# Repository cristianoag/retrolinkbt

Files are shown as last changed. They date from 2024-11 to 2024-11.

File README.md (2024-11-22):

# RetroLinkBT
Simple adapter to allow the use of bluetooth joysticks with retro computers

## License 

Open Hardware

This work is licensed under a [Creative Commons Attribution-NonCommercial-ShareAlike 4.0 International License](http://creativecommons.org/licenses/by-nc-sa/4.0/).

* If you remix, transform, or build upon the material, you must distribute your contributions under the same license as the original.
* You may not use the material for commercial purposes.
* You must give appropriate credit, provide a link to the license, and indicate if changes were made. You may do so in any reasonable manner, but not in any way that suggests the licensor endorses you or your use.

**ATTENTION**

This project was made for the retro community and not for commercial purposes. So only retro hardware forums and individual people can build this project.

THE SALE OF ANY PART OF THIS PROJECT WITHOUT EXPRESS AUTHORIZATION IS PROHIBITED!

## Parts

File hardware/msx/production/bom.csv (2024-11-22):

Designator | Footprint | Quantity | Value | LCSC Part #
C1, C11, C12, C6, C7, C9 | 0603 | 6 | 0.1uF
C10, C4, C5, C8 | 0603 | 4 | 22uF
C3 | 0603 | 1 | 1uF
D1 | 0805 | 1 | PWR
D2 | 0805 | 1 | Port1
D3 | 0805 | 1 | BT DISC
D4, D5 | D_SOD-123 | 2 | 1N5819
F1 | 1206 | 1 | 50mA
J1 | USB_Mini-B_Lumberg_2486_01_Horizontal | 1 | USB_B_Mini
J2 | DSUB-9_Female_Horizontal_P2.77x2.84mm_EdgePinOffset4.94mm_Housed_MountingHolesOffset7.48mm | 1 | MSX Port1
JP1 | PinHeader_1x02_P2.54mm_Vertical | 1 | Fuse Bypass
JP2, JP4 | SolderJumper-2_P1.3mm_Open_RoundedPad1.0x1.5mm | 2 | Open
Q1, Q2 | SOT-23 | 2 | S8050
R1, R2 | 0603 | 2 | 1K
R10, R5, R9 | 0603 | 3 | 3.3K
R11, R3, R4, R8 | 0603 | 4 | 10K
R12, R6 | 0603 | 2 | 3.3K | C4310
R7 | 0603 | 1 | 1K | C4310
SW1 | SK12D07VG4 | 1 | SK12D07VG4
SW2 | SW_SPST_TL3342 | 1 | RESET
SW3 | SW_SPST_TL3342 | 1 | BOOT
U1 | SOIC-16_3.9x9.9mm_P1.27mm | 1 | CH340C
U2 | SOT-223-3_TabPin2 | 1 | AMS1117-3.3
U3 | ESP32-WROOM-32E | 1 | ESP32-WROOM-32E | C701341
U4, U5 | SOIC-14_3.9x8.7mm_P1.27mm | 2 | 74LS03

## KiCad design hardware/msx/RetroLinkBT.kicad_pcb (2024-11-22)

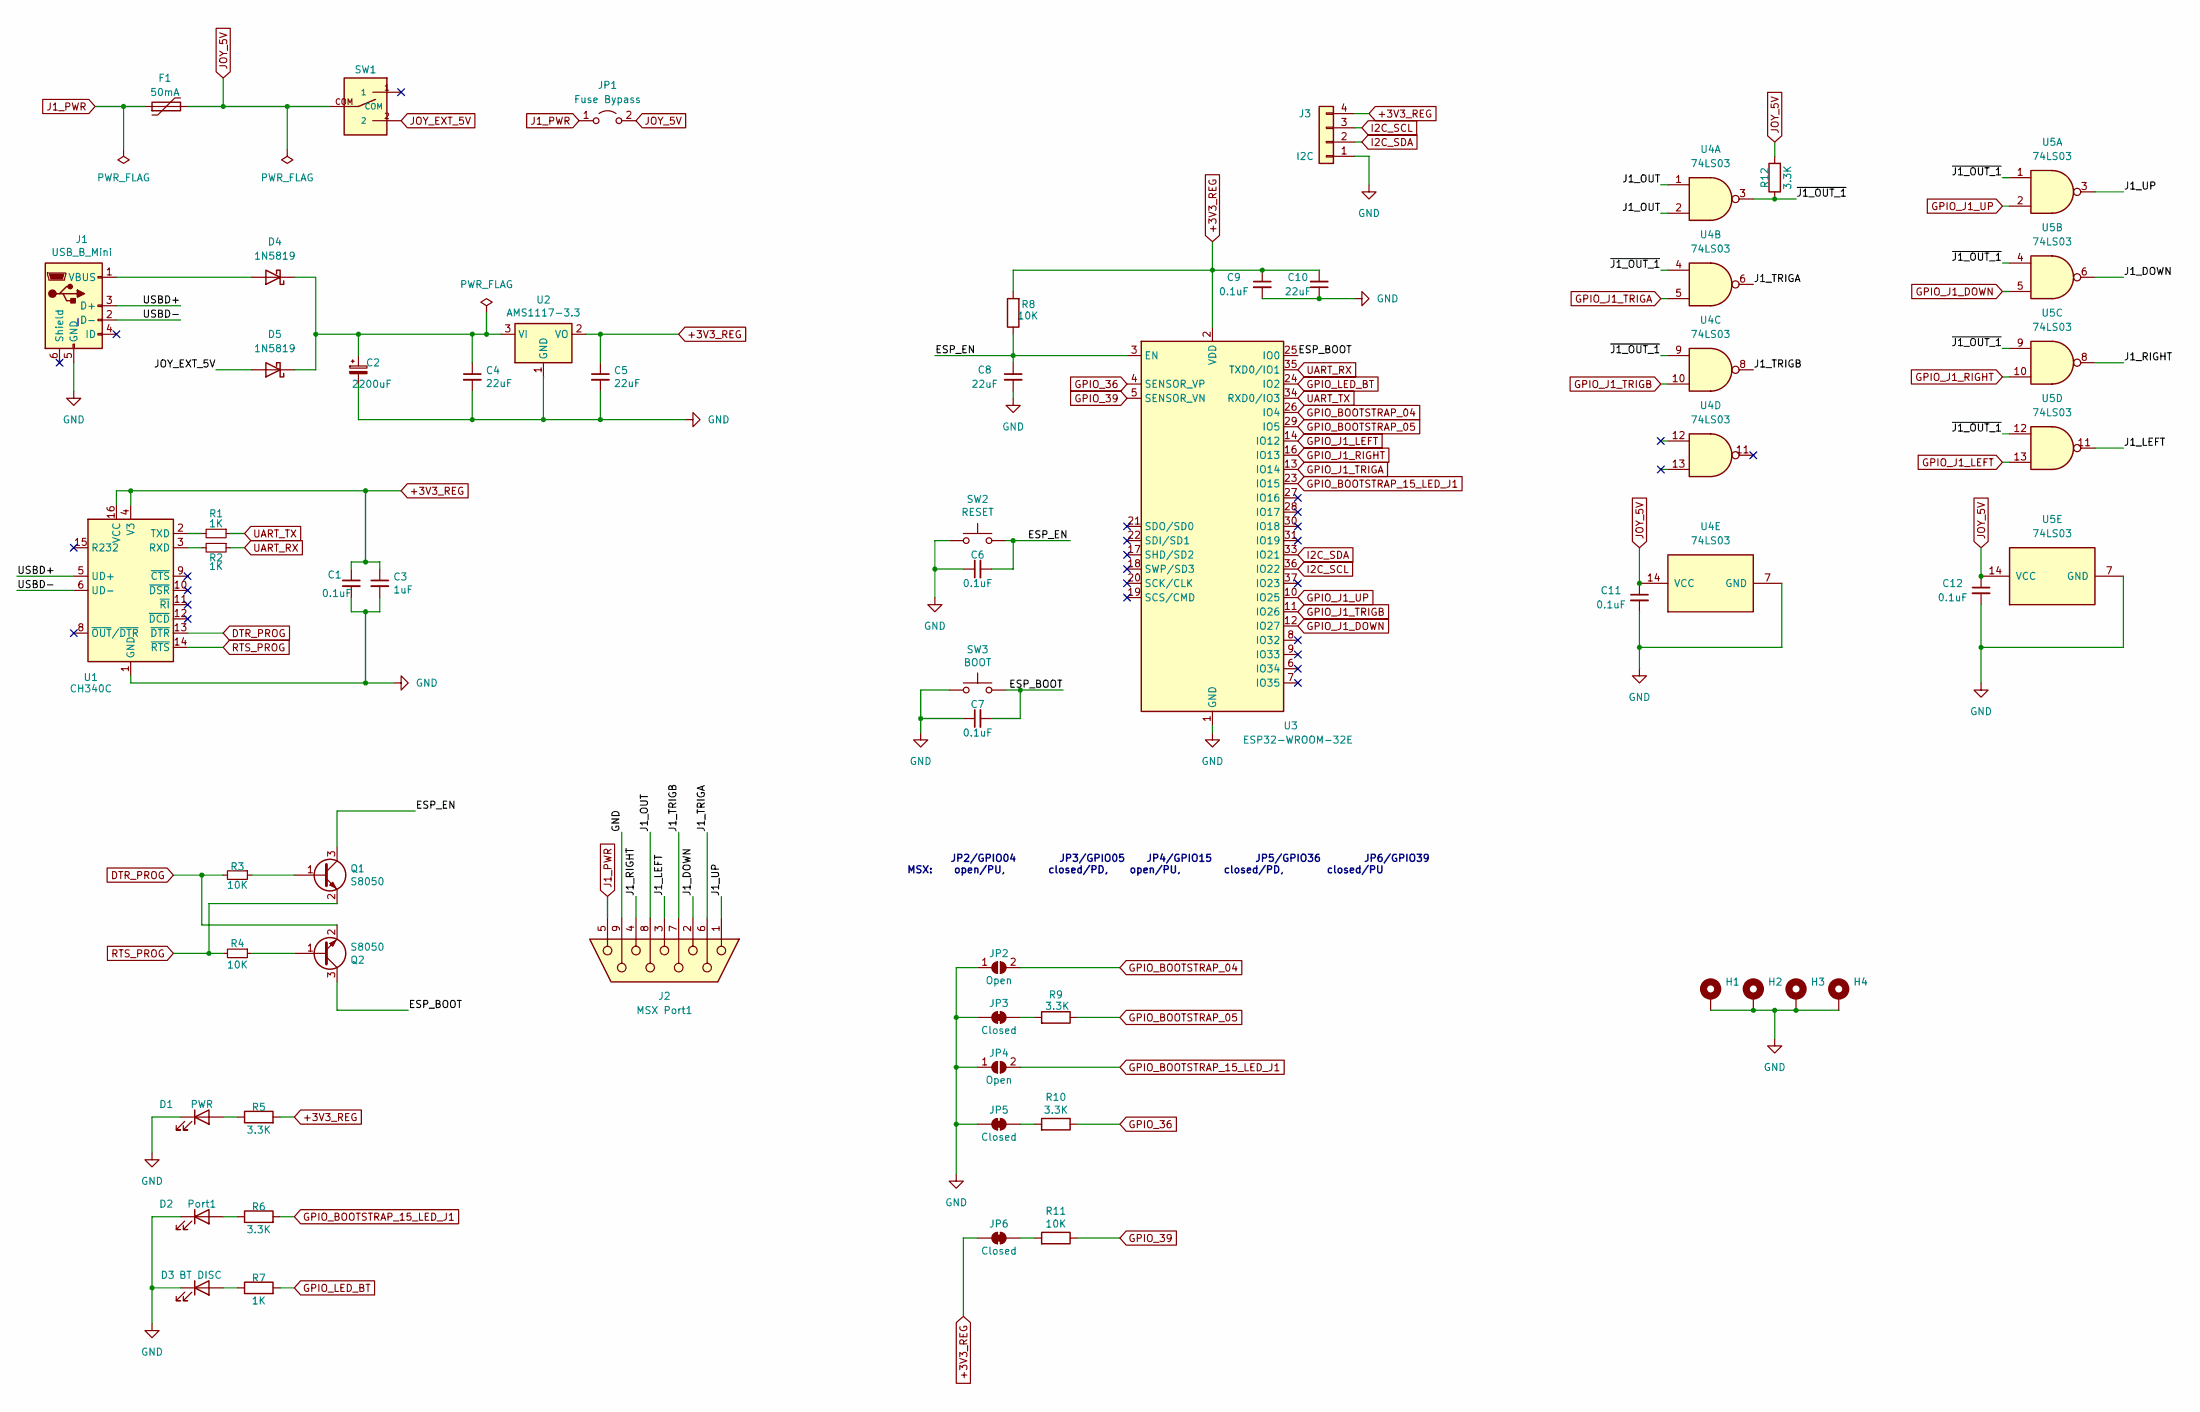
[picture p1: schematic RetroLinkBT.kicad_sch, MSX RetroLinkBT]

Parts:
C1, C6, C7, C9, C11, C12: 0.1uF; C_0603_1608Metric_Pad1.08x0.95mm_HandSolder
C2: 2200uF; CP_Elec_10x10.5
C3: 1uF; C_0603_1608Metric_Pad1.08x0.95mm_HandSolder
C4, C5, C8, C10: 22uF; C_0603_1608Metric_Pad1.08x0.95mm_HandSolder
D1: PWR; LED_0805_2012Metric_Pad1.15x1.40mm_HandSolder
D2: Port1; LED_0805_2012Metric_Pad1.15x1.40mm_HandSolder
D3: BT DISC; LED_0805_2012Metric_Pad1.15x1.40mm_HandSolder
D4, D5: 1N5819; D_SOD-123
F1: 50mA; Fuse_1206_3216Metric_Pad1.42x1.75mm_HandSolder
H1, H2, H3, H4: MountingHole_Pad; MountingHole_3.2mm_M3
J1: USB_B_Mini; USB_Mini-B_Lumberg_2486_01_Horizontal
J2: MSX Port1; DSUB-9_Female_Horizontal_P2.77x2.84mm_EdgePinOffset4.94mm_H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
J3: I2C; JST_PH_B4B-PH-K_1x04_P2.00mm_Vertical
JP1: Fuse Bypass; PinHeader_1x02_P2.54mm_Vertical
JP2, JP4: Open; SolderJumper-2_P1.3mm_Open_RoundedPad1.0x1.5mm
JP3, JP5, JP6: Closed; SolderJumper-2_P1.3mm_Bridged_RoundedPad1.0x1.5mm
Q1, Q2: S8050; SOT-23
R1, R2: 1K; R_0603_1608Metric_Pad0.98x0.95mm_HandSolder
R3, R4, R8, R11: 10K; R_0603_1608Metric_Pad0.98x0.95mm_HandSolder
R5, R9, R10: 3.3K; R_0603_1608Metric_Pad0.98x0.95mm_HandSolder
R6, R12: 3.3K; R_0603_1608Metric_Pad0.98x0.95mm_HandSolder; LCSC C4310
R7: 1K; R_0603_1608Metric_Pad0.98x0.95mm_HandSolder; LCSC C4310
SW1: SK12D07VG4
SW2: RESET; SW_SPST_TL3342
SW3: BOOT; SW_SPST_TL3342
U1: CH340C; SOIC-16_3.9x9.9mm_P1.27mm
U2: AMS1117-3.3; SOT-223-3_TabPin2
U3: ESP32-WROOM-32E; LCSC C701341
U4, U5: 74LS03; SOIC-14_3.9x8.7mm_P1.27mm

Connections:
+3V3_REG: C1.1, C3.1, C5.1, C9.1, C10.2, J3.4, JP6.1 (A), R5.2, R8.2, U1.4 (V3), U1.16 (VCC), U2.2 (VO), U3.2 (VDD)
/ESP_BOOT: C7.2, Q2.3 (C), SW3.2, U3.25 (IO0)
/ESP_EN: C6.2, C8.1, Q1.3 (C), R8.1, SW2.2, U3.3 (EN)
/J1_DOWN: J2.2, U5.6
/J1_LEFT: J2.3, U5.11
/J1_OUT: J2.8, U4.1, U4.2
/J1_RIGHT: J2.4, U5.8
/J1_TRIGA: J2.6, U4.6
/J1_TRIGB: J2.7, U4.8
/J1_UP: J2.1, U5.3
/USBD+: J1.3 (D+), U1.5 (UD+)
/USBD-: J1.2 (D-), U1.6 (UD-)
/~J1_OUT_1: R12.1, U4.3, U4.4, U4.9, U5.1, U5.4, U5.9, U5.12
DTR_PROG: Q2.2 (E), R3.2, U1.13 (~DTR)
GND: C1.2, C2.2, C3.2, C4.2, C5.2, C6.1, C7.1, C8.2, C9.2, C10.1, C11.2, C12.2, D1.1 (K), D2.1 (K), D3.1 (K), H1.1, H2.1, H3.1, H4.1, J1.5 (GND), J2.9, J3.1, JP2.1 (A), JP3.1 (A), JP4.1 (A), JP5.1 (A), SW2.1, SW3.1, U1.1 (GND), U2.1 (GND), U3.1 (GND), U3.15 (GND), U3.38 (GND), U3.39 (GND), U4.7 (GND), U5.7 (GND)
GPIO_36: R10.1, U3.4 (SENSOR_VP)
GPIO_39: R11.1, U3.5 (SENSOR_VN)
GPIO_BOOTSTRAP_04: JP2.2 (B), U3.26 (IO4)
GPIO_BOOTSTRAP_05: R9.1, U3.29 (IO5)
GPIO_BOOTSTRAP_15_LED_J1: JP4.2 (B), R6.2, U3.23 (IO15)
GPIO_J1_DOWN: U3.12 (IO27), U5.5
GPIO_J1_LEFT: U3.14 (IO12), U5.13
GPIO_J1_RIGHT: U3.16 (IO13), U5.10
GPIO_J1_TRIGA: U3.13 (IO14), U4.5
GPIO_J1_TRIGB: U3.11 (IO26), U4.10
GPIO_J1_UP: U3.10 (IO25), U5.2
GPIO_LED_BT: R7.2, U3.24 (IO2)
I2C_SCL: J3.3, U3.36 (IO22)
I2C_SDA: J3.2, U3.33 (IO21)
J1_PWR: F1.1, J2.5, JP1.1 (A)
JOY_5V: C11.1, C12.1, F1.2, JP1.2 (B), R12.2, SW1.COM, U4.14 (VCC), U5.14 (VCC)
JOY_EXT_5V: D5.2 (A), SW1.2
unnamed: D1.2 (A), R5.1
unnamed: D2.2 (A), R6.1
unnamed: D3.2 (A), R7.1
unnamed: D4.2 (A), J1.1 (VBUS)
unnamed: C2.1, C4.1, D4.1 (K), D5.1 (K), U2.3 (VI)
unnamed: JP3.2 (B), R9.2
unnamed: JP5.2 (B), R10.2
unnamed: JP6.2 (B), R11.2
unnamed: Q1.1 (B), R3.1
unnamed: Q2.1 (B), R4.1
unnamed: R2.2, U1.3 (RXD)
unnamed: R1.2, U1.2 (TXD)
RTS_PROG: Q1.2 (E), R4.2, U1.14 (~RTS)
UART_RX: R2.1, U3.35 (TXD0/IO1)
UART_TX: R1.1, U3.34 (RXD0/IO3)

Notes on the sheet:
JP2/GPIO04 JP3/GPIO05 JP4/GPIO15 JP5/GPIO36 JP6/GPIO39 MSX: open/PU, closed/PD, open/PU, closed/PD, closed/PU

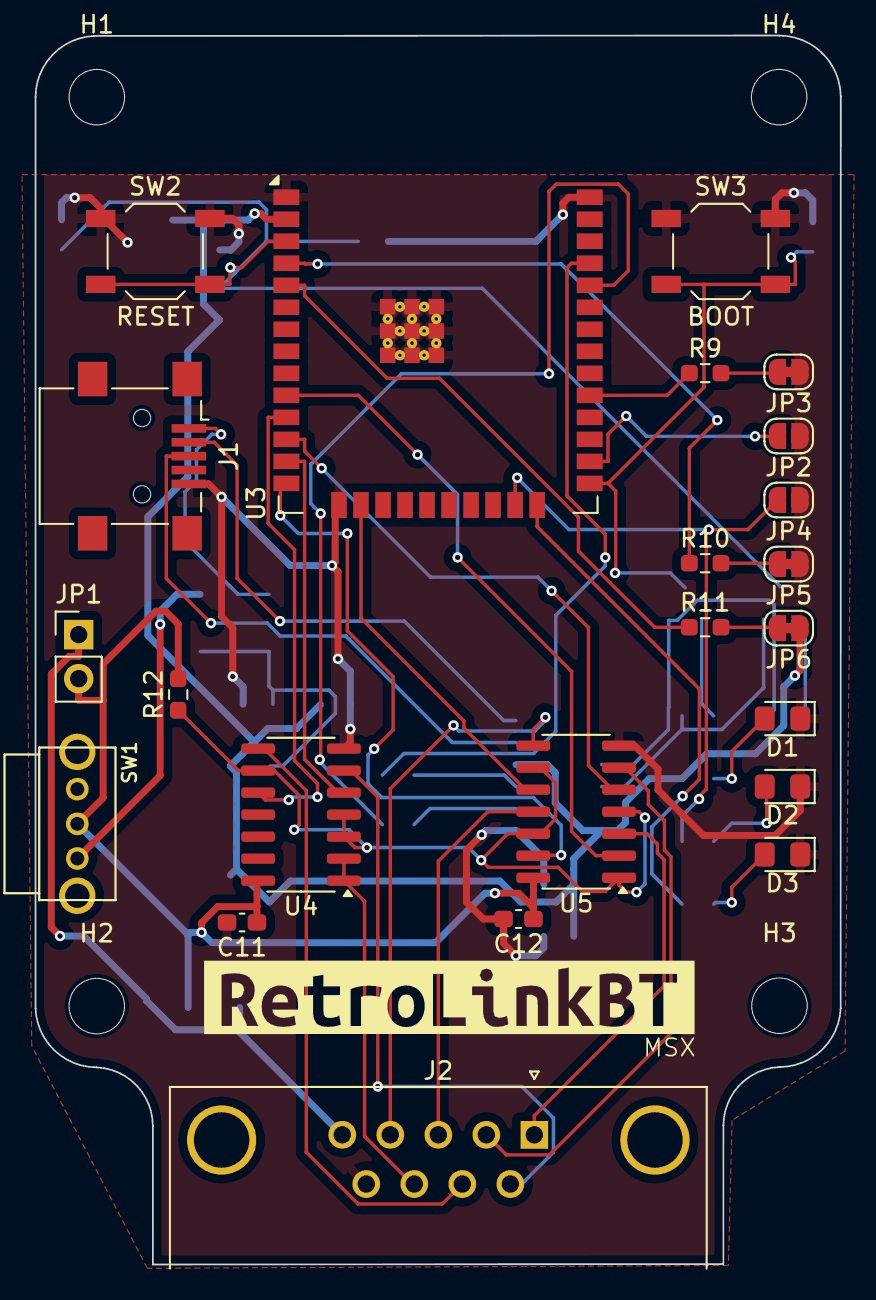
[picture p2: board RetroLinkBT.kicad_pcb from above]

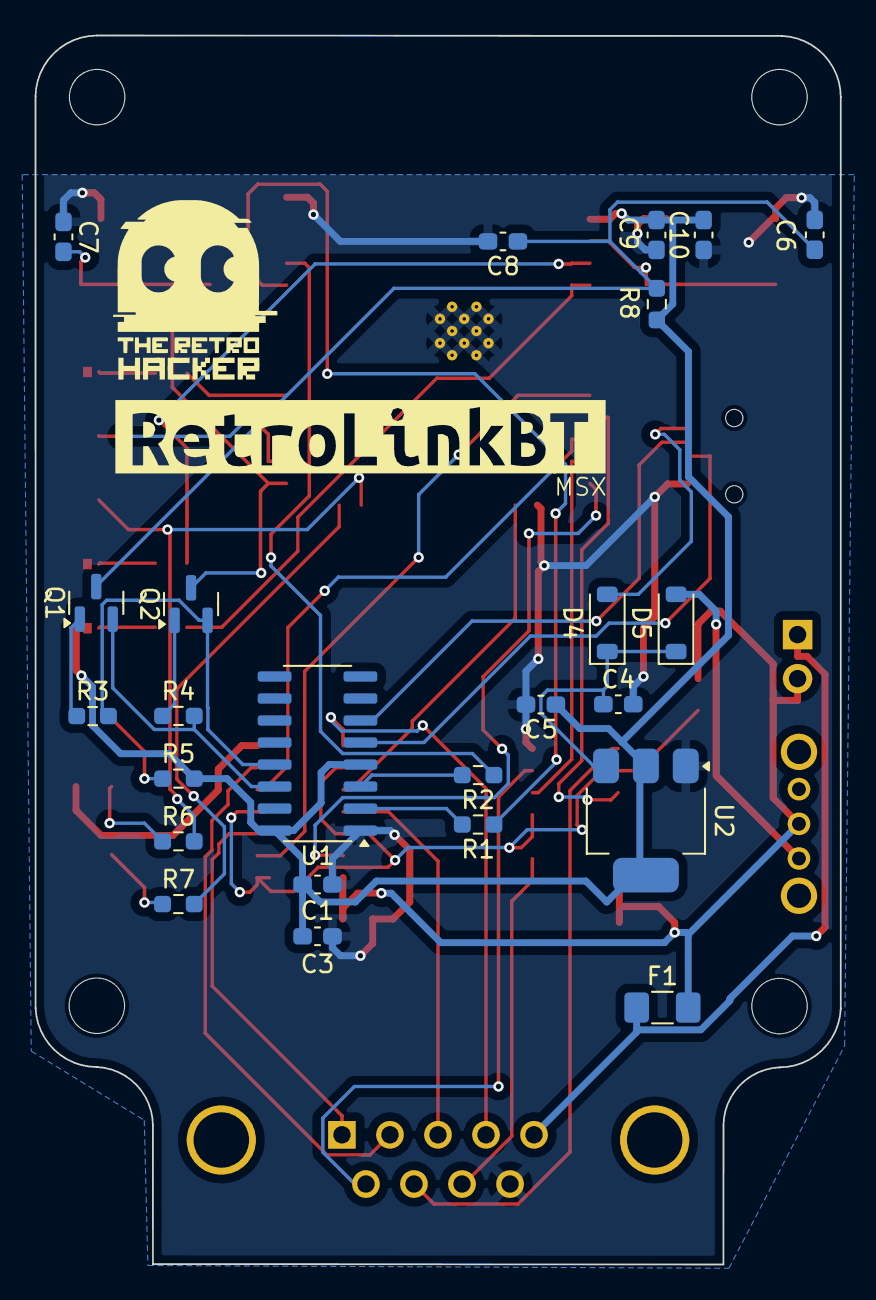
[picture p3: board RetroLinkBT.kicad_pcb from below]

Board: 2 copper layers, 46.5 x 70.9 mm, 53 parts (25 on the bottom side), 45 nets.

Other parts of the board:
kibuzzard-673FD7EF, kibuzzard-673FD7EF#2: G***; kibuzzard-673FD7EF
